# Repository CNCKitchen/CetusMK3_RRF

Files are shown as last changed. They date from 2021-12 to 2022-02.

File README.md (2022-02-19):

# CetusMK3_RRF
Cetus MK3 conversion to a RepRapFirmware mainboard.
# Introduction
This repository contains all the files and resources I used to convert my CETUS MK3 to a RepRapFirmware mainboard, more precisely the Mellow FLY RRF E3.
# Contents
## Adapter Board
Contains the KiCAD and GERBER files to manufacture your own board.
## Holder
Contains different holders to mount the adapter board and the new mainboard. Available versions:
- Mellow Fly RRF E3 (and E3 Pro)
## PrusaSlicer Profile
Contains the PS profile with wich I did most of my prints. Created with PS2.4 Beta but should also be back-compatible.
## RRF Configuration
Contains the configuration files for Reprap Firmware.
- Created for RepRap Firmware 3.4
- Created for Mellow Fly RRF E3
- Thermistor of the hotend was swapped to a standard E3D cartrige style thermistor

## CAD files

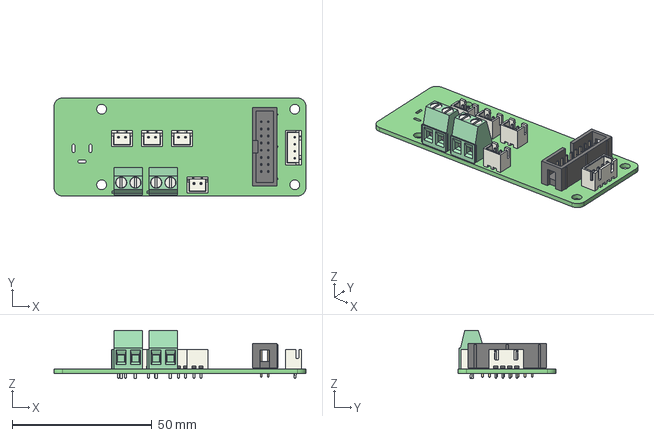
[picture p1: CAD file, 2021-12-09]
AdapterBoard/adapter01.step
90.0 x 35.0 x 17.3 mm

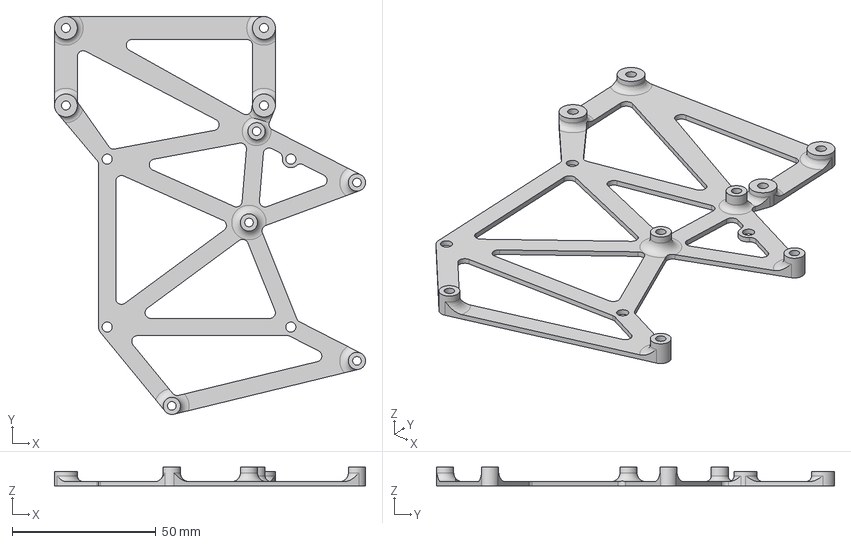
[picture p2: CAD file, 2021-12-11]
Holder/holder_MellowFLY.step
108.4 x 138.7 x 6.50 mm

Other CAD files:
Holder/Holder_MellowFlyRRFE3.stl
Holder/holder_MellowFLY.f3z

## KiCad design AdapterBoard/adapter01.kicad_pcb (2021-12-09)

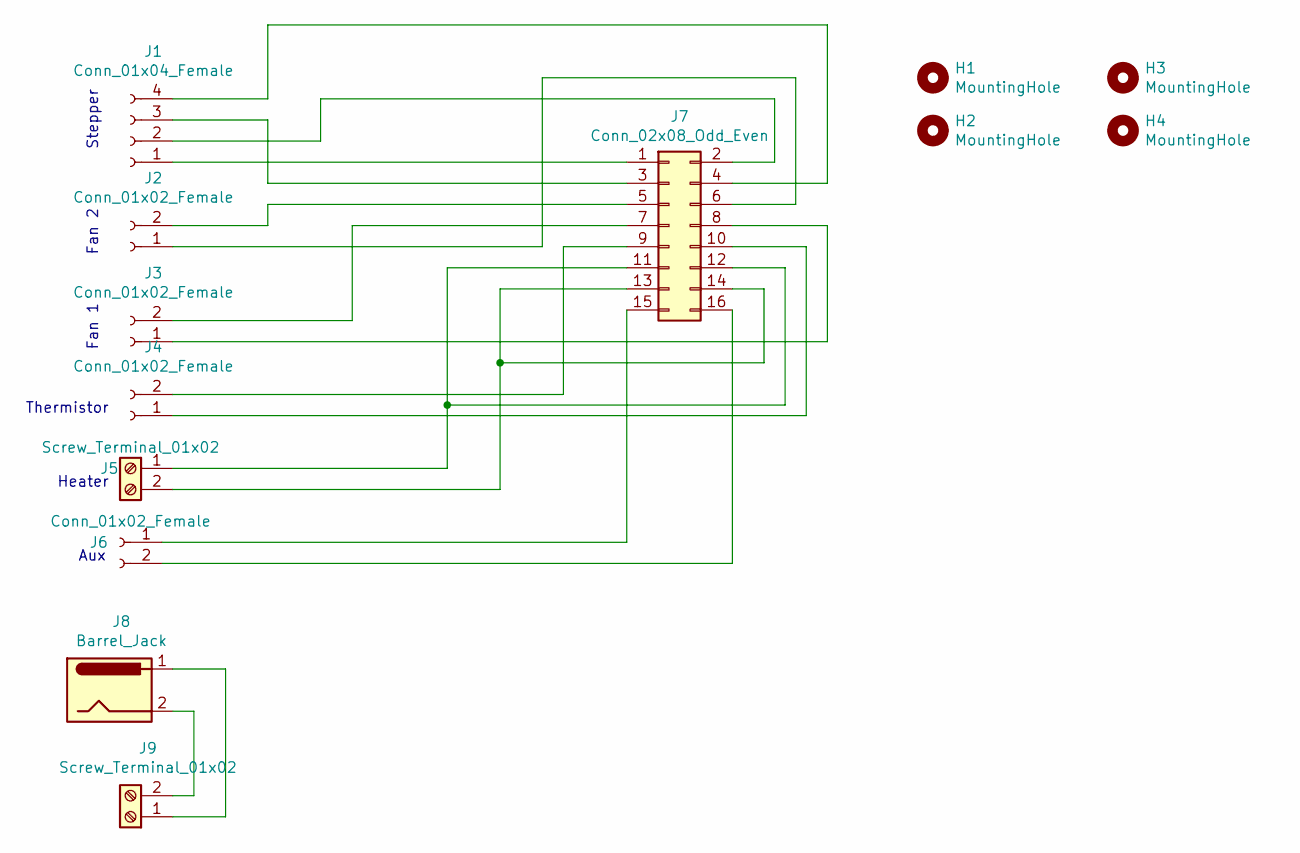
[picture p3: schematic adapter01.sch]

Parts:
H1, H2, H3, H4: MountingHole; MountingHole_3.5mm
J1: Conn_01x04_Female; JST_XH_B4B-XH-A_1x04_P2.50mm_Vertical
J2, J3, J4, J6: Conn_01x02_Female; JST_XH_B2B-XH-A_1x02_P2.50mm_Vertical
J5, J9: Screw_Terminal_01x02; TerminalBlock_Phoenix_MKDS-1,5-2-5.08_1x02_P5.08mm_Horizont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
J7: Conn_02x08_Odd_Even; IDC-Header_2x08_P2.54mm_Vertical
J8: Barrel_Jack; BarrelJack_Horizontal

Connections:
unnamed: J1.1, J7.1
unnamed: J1.2, J7.2
unnamed: J1.3, J7.3
unnamed: J1.4, J7.4
unnamed: J2.1, J7.6
unnamed: J2.2, J7.5
unnamed: J3.1, J7.8
unnamed: J3.2, J7.7
unnamed: J4.1, J7.10
unnamed: J4.2, J7.9
unnamed: J5.1, J7.11, J7.12
unnamed: J5.2, J7.13, J7.14
unnamed: J6.1, J7.15
unnamed: J6.2, J7.16
unnamed: J8.1, J9.1
unnamed: J8.2, J9.2

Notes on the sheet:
Stepper
Fan 2
Fan 1
Thermistor
Heater
Aux

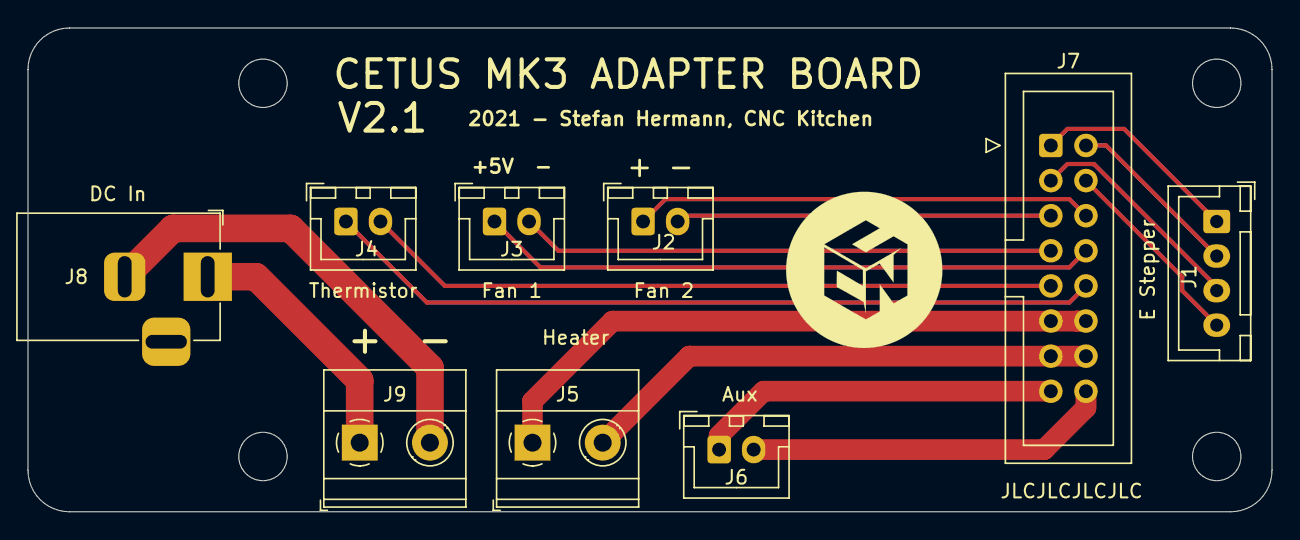
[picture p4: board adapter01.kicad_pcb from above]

Board: 2 copper layers, 90.0 x 35.0 mm, 13 parts (0 on the bottom side), 16 nets.

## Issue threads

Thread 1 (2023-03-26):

Cetus MK2 conversion instructions and files

mtchetch, 2023-03-26:
Hi,

You inspired me to convert my Cetus MK2 Extended to the E3 Fly Pro V3 board and RRF firmware. It has been a fun project and I wanted to contribute back to the community. Since you have positioned yourself as the goto Cetus converter, it would be nice to add my Cetus mk2 stuff to yours so people have an easier time embarking on such a project.

I have a pullrequest riding on the gloomy community configs repository: https://github.com/TeamGloomy/LPC-STM32-RRFUserConfigs/pull/28

I included some rudimentary documentation and pinouts that could be helpfull. Any ideas on the best way forward?

mtchetch, 2023-03-28:
That would be nice and probably helpful to others if someone wants to convert their Cetus MK2. I will add more photos to the docs later on when I have the time.

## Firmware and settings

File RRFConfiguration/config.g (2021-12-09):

; Configuration file for Fly-E3 (firmware version 3)
; executed by the firmware on start-up
;
; generated by RepRapFirmware Configuration Tool v3.3.0-LPC-STM32+01 on Thu Aug 26 2021 10:34:21 GMT+0200 (Mitteleuropäische Sommerzeit)

; General preferences
G90                                           ; send absolute coordinates...
M83                                           ; ...but relative extruder moves
M550 P"CetusRRF"                              ; set printer name

; Network
M552 S1                                       ; enable network
M586 P0 S1                                    ; enable HTTP
M586 P1 S0                                    ; disable FTP
M586 P2 S0                                    ; disable Telnet

; Drives
M569 P0 S0 V10                                   ; physical drive 0 goes forwards using default driver timings
M569 P1 S1 V10                                   ; physical drive 1 goes forwards using default driver timings
M569 P2 S1 V10                                   ; physical drive 2 goes forwards using default driver timings
M569 P3 S0 V10                                   ; physical drive 3 goes forwards using default driver timings
M584 X0 Y1 Z2 E3                              ; set drive mapping
M350 X32 Y32 Z32 E32 I0                       ; configure microstepping with interpolation
M92 X160.00 Y160.00 Z160.00 E204             ; set steps per mm
M566 X900.00 Y900.00 Z600.00 E1000.00          ; set maximum instantaneous speed changes (mm/min)
M203 X10000.00 Y10000.00 Z3000.00 E5000.00      ; set maximum speeds (mm/min)
M201 X10000.00 Y10000.00 Z2000.00 E1000.00          ; set accelerations (mm/s^2)
M906 X500 Y500 Z650 E450 I30                  ; set motor currents (mA) and motor idle factor in per cent
M84 S30                                       ; Set idle timeout

; Axis Limits
M208 X0 Y0 Z0 S1                              ; set axis minima
M208 X180 Y180 Z186 S0                        ; set axis maxima

; Endstops
M574 X1 S1 P"xstop"                           ; configure active-high endstop for high end on X via pin xstop
M574 Y1 S1 P"ystop"                           ; configure active-high endstop for low end on Y via pin ystop
M574 Z2 S1 P"zstop"                           ; configure active-high endstop for high end on Z via pin zstop

; Z-Probe
M558 P0 H5 F120 T6000                         ; disable Z probe but set dive height, probe speed and travel speed
M557 X15:165 Y15:165 P3                      ; define mesh grid
M376 H5										 ; Fade height 5mm

; Heaters
M140 H-1                                      ; disable heated bed (overrides default heater mapping)
M308 S0 P"e0temp" Y"thermistor" T100000 B4725 C7.06e-8 ; configure sensor 0 as thermistor on pin e0temp
M950 H0 C"e0heat" T0                          ; create nozzle heater output on e0heat and map it to sensor 0
M307 H0 B0 R2.103 C186.2 D5.55 S1.00 V24.0
M143 H0 S250                                  ; set temperature limit for heater 0 to 250C

; Fans
M950 F0 C"fan0" Q500                          ; create fan 0 on pin fan0 and set its frequency
M106 P0 S1.0 H0 T50                              ; set fan 0 value. Thermostatic control is turned on

; Tools
M563 P0 D0 H0 F0                              ; define tool 0
G10 P0 X0 Y0 Z0.3                             ; set tool 0 axis offsets
G10 P0 R0 S0                                  ; set initial tool 0 active and standby temperatures to 0C

; Accelerometer
M955 P0 C"E.8+B.1" I20

;Input shaper
M593 P"zdv" F21 S0.1 L10
;M593 P"none"

; Miscellaneous
M572 D0 S0.13
;M572 D0 S0
T0                                            ; select first tool 

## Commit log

2021-12-11 added PrusaSlicer profile 0.2mm
2021-12-11 Added CAD models
    [holder_MellowFLY.f3z, holder_MellowFLY.step]
